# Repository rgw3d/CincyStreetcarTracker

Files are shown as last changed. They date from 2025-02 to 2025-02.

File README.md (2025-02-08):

# Cincinnati Streetcar Tracker

I learned that the real-time transit information for the Cincinnati Streetcar was published by Metro here: https://www.go-metro.com/about/developer-data/ in [GTFS](https://en.wikipedia.org/wiki/GTFS) form. 

And then I saw https://www.traintrackr.io/ and was inspired to make a version for Cincinnati. 

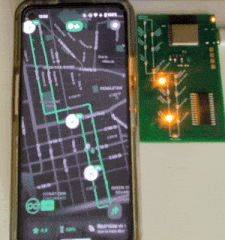
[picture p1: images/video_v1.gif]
Gif of the board in action

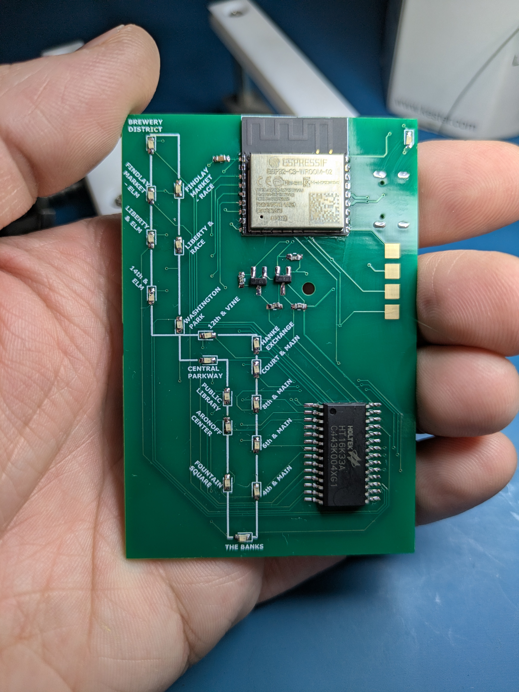
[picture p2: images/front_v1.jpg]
Front of the V1 board

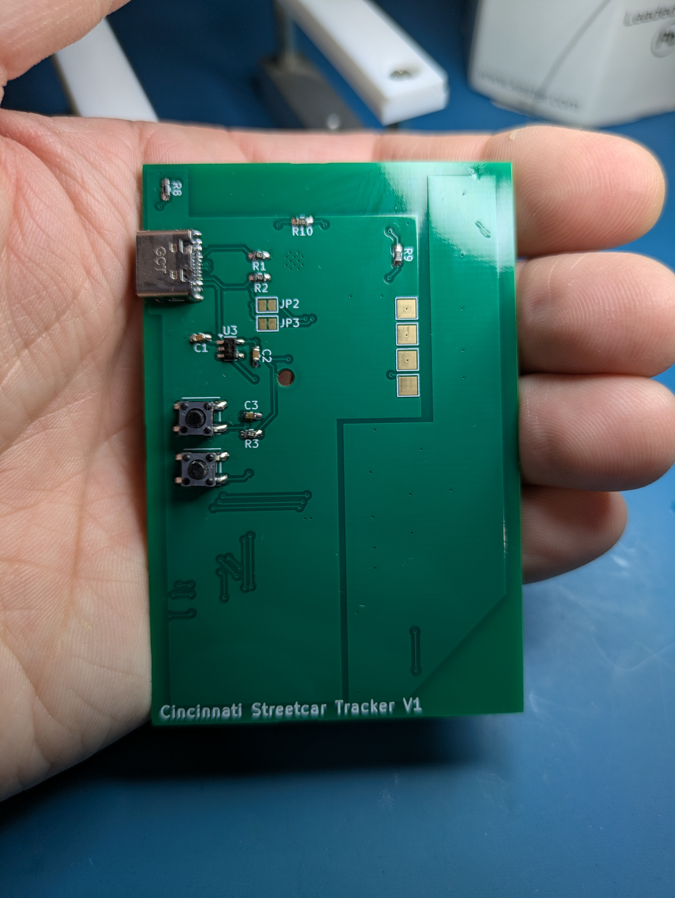
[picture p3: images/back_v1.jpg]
Back of the V1 board


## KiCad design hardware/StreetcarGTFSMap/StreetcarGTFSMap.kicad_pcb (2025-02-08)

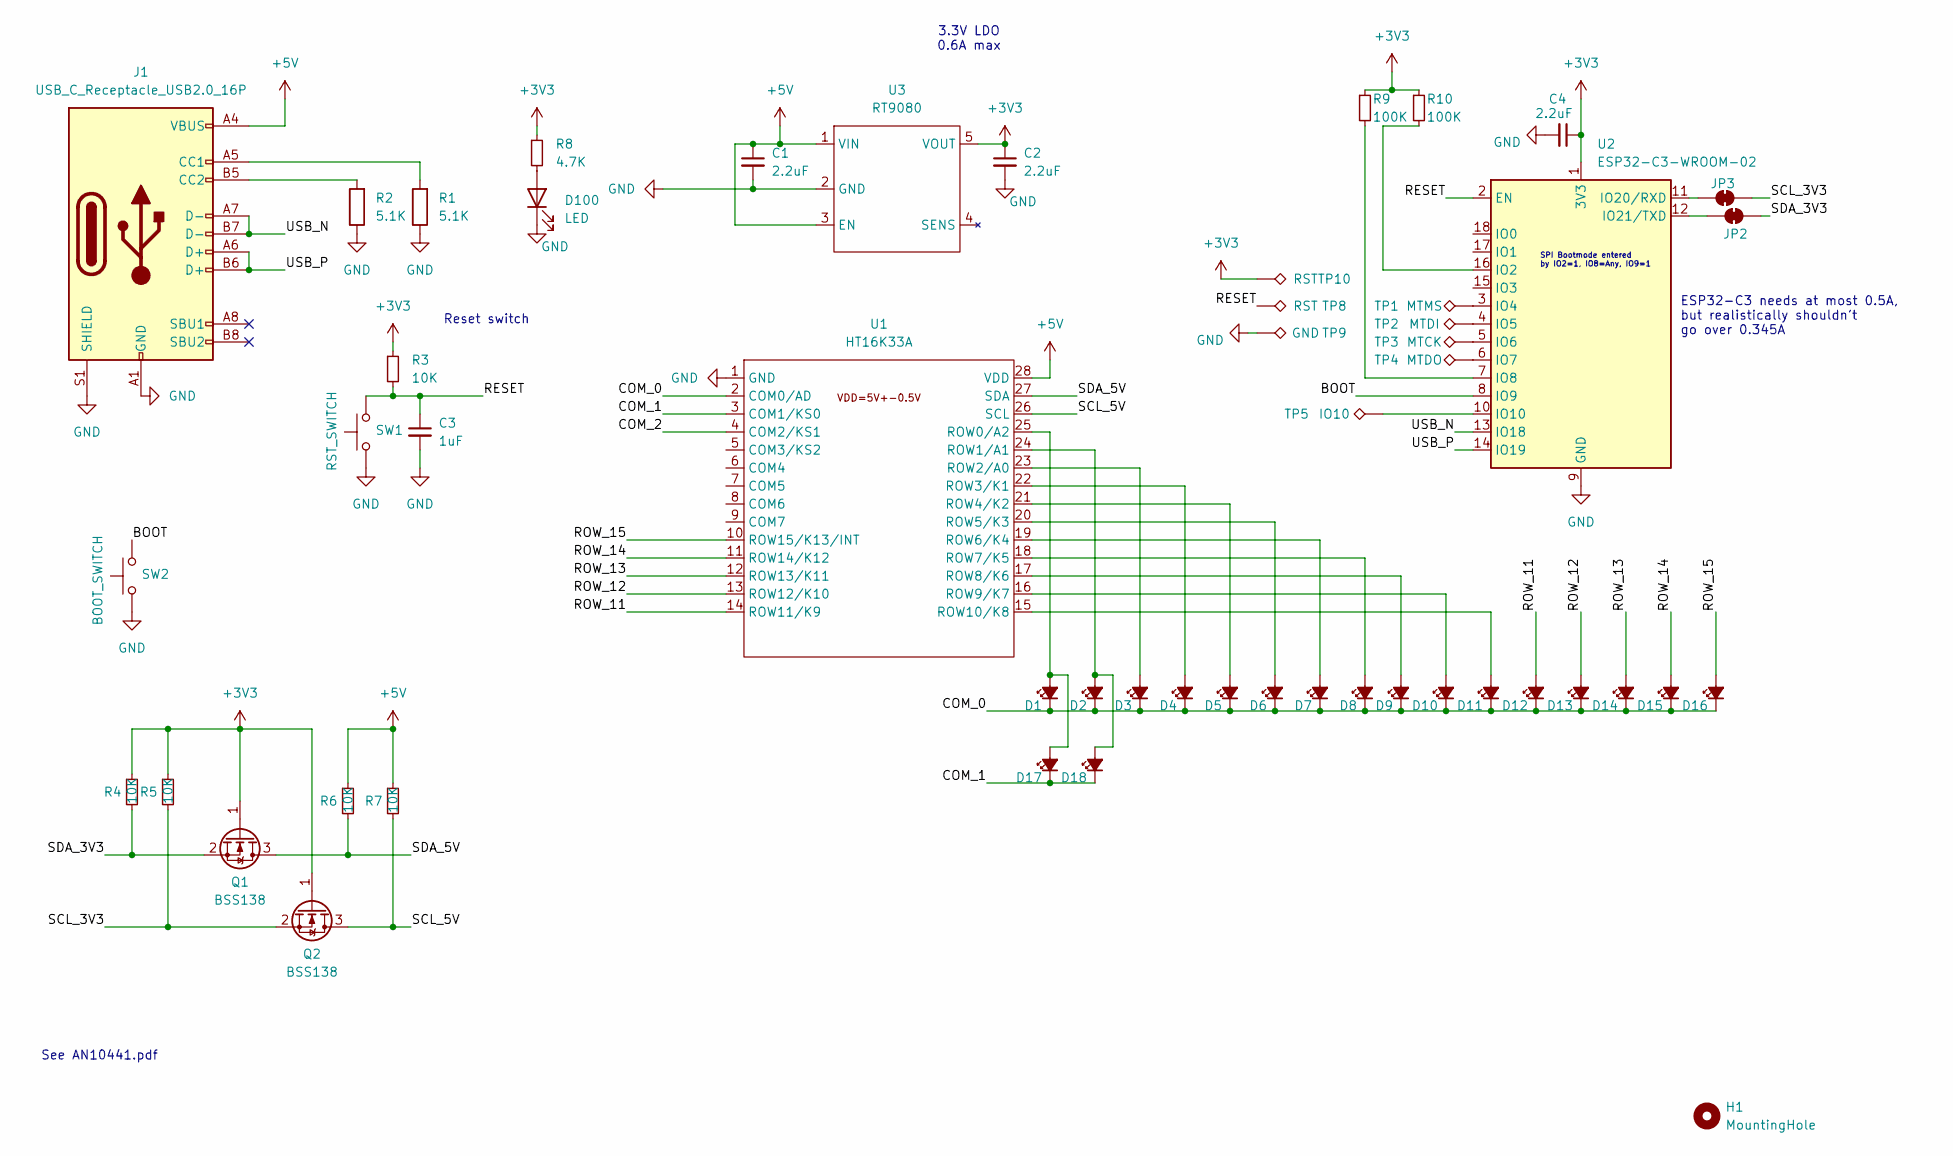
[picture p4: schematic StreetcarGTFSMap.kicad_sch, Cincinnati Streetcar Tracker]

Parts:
C1, C2, C4: 2.2uF; C_0603_1608Metric_Pad1.08x0.95mm_HandSolder
C3: 1uF; C_0603_1608Metric_Pad1.08x0.95mm_HandSolder
D1, D2, D3, D4, D5, D6, D7, D8, D9, D10, D11, D12, D13, D14, D15, D16, D17, D18: LED_Small_Filled; LED_0603_1608Metric_Pad1.05x0.95mm_HandSolder
D100: LED; LED_0603_1608Metric_Pad1.05x0.95mm_HandSolder
H1: MountingHole; MountingHole_2.1mm
J1: USB_C_Receptacle_USB2.0_16P; USB_C_Receptacle_GCT_USB4105-xx-A_16P_TopMnt_Horizontal
JP2, JP3: SolderJumper_2_Bridged; SolderJumper-2_P1.3mm_Bridged_Pad1.0x1.5mm
Q1, Q2: BSS138; SOT-23_Handsoldering
R1, R2: 5.1K; R_0603_1608Metric_Pad0.98x0.95mm_HandSolder
R3, R4, R5, R6, R7: 10K; R_0603_1608Metric_Pad0.98x0.95mm_HandSolder
R8: 4.7K; R_0603_1608Metric_Pad0.98x0.95mm_HandSolder
R9, R10: 100K; R_0603_1608Metric_Pad0.98x0.95mm_HandSolder
SW1: RST_SWITCH; SW_SPST_PTS647_Sx50
SW2: BOOT_SWITCH; SW_SPST_PTS647_Sx50
TP1: MTMS; TestPoint_Pad_2.5x2.5mm
TP2: MTDI; TestPoint_Pad_2.5x2.5mm
TP3: MTCK; TestPoint_Pad_2.5x2.5mm
TP4: MTDO; TestPoint_Pad_2.5x2.5mm
TP5: IO10; TestPoint_Pad_2.5x2.5mm
TP8, TP10: RST; TestPoint_Pad_2.5x2.5mm
TP9: GND; TestPoint_Pad_2.5x2.5mm
U1: HT16K33A; SOP-28_8.4x18.16mm_P1.27mm
U2: ESP32-C3-WROOM-02
U3: RT9080; TSOT-23-5

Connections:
+3V3: C2.1, C4.1, Q1.1 (G), Q2.1 (G), R3.1, R4.1, R5.1, R8.1, R9.1, R10.1, TP10.1, U2.1 (3V3), U3.5 (VOUT)
+5V: C1.1, J1.A4 (VBUS), J1.A9 (VBUS), J1.B4 (VBUS), J1.B9 (VBUS), R6.1, R7.1, U1.28 (VDD), U3.1 (VIN), U3.3 (EN)
/BOOT: SW2.2, U2.8 (IO9)
/COM_0: D1.1 (K), D2.1 (K), D3.1 (K), D4.1 (K), D5.1 (K), D6.1 (K), D7.1 (K), D8.1 (K), D9.1 (K), D10.1 (K), D11.1 (K), D12.1 (K), D13.1 (K), D14.1 (K), D15.1 (K), D16.1 (K), U1.2 (COM0/AD)
/COM_1: D17.1 (K), D18.1 (K), U1.3 (COM1/KS0)
/COM_2: U1.4 (COM2/KS1)
/RESET: C3.1, R3.2, SW1.2, TP8.1, U2.2 (EN)
/ROW_11: D12.2 (A), U1.14 (ROW11/K9)
/ROW_12: D13.2 (A), U1.13 (ROW12/K10)
/ROW_13: D14.2 (A), U1.12 (ROW13/K11)
/ROW_14: D15.2 (A), U1.11 (ROW14/K12)
/ROW_15: D16.2 (A), U1.10 (ROW15/K13/INT)
/SCL_3V3: JP3.2 (B), Q2.2 (S), R5.2
/SCL_5V: Q2.3 (D), R7.2, U1.26 (SCL)
/SDA_3V3: JP2.2 (B), Q1.2 (S), R4.2
/SDA_5V: Q1.3 (D), R6.2, U1.27 (SDA)
/USB_N: J1.A7 (D-), J1.B7 (D-), U2.13 (IO18)
/USB_P: J1.A6 (D+), J1.B6 (D+), U2.14 (IO19)
GND: C1.2, C2.2, C3.2, C4.2, D100.1 (K), J1.A1 (GND), J1.A12 (GND), J1.B1 (GND), J1.B12 (GND), J1.S1 (SHIELD), R1.1, R2.1, SW1.1, SW2.1, TP9.1, U1.1 (GND), U2.9 (GND), U2.19 (GND), U3.2 (GND)
unnamed: D1.2 (A), D17.2 (A), U1.25 (ROW0/A2)
unnamed: D3.2 (A), U1.23 (ROW2/A0)
unnamed: D4.2 (A), U1.22 (ROW3/K1)
unnamed: D5.2 (A), U1.21 (ROW4/K2)
unnamed: D6.2 (A), U1.20 (ROW5/K3)
unnamed: D7.2 (A), U1.19 (ROW6/K4)
unnamed: D8.2 (A), U1.18 (ROW7/K5)
unnamed: D9.2 (A), U1.17 (ROW8/K6)
unnamed: D10.2 (A), U1.16 (ROW9/K7)
unnamed: D11.2 (A), U1.15 (ROW10/K8)
unnamed: D2.2 (A), D18.2 (A), U1.24 (ROW1/A1)
unnamed: D100.2 (A), R8.2
unnamed: J1.A5 (CC1), R1.2
unnamed: J1.B5 (CC2), R2.2
unnamed: JP2.1 (A), U2.12 (IO21/TXD)
unnamed: JP3.1 (A), U2.11 (IO20/RXD)
unnamed: R10.2, U2.16 (IO2)
unnamed: TP1.1, U2.3 (IO4)
unnamed: TP2.1, U2.4 (IO5)
unnamed: TP3.1, U2.5 (IO6)
unnamed: TP4.1, U2.6 (IO7)
unnamed: R9.2, U2.7 (IO8)
unnamed: TP5.1, U2.10 (IO10)

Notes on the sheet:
Reset switch
3.3V LDO 0.6A max
ESP32-C3 needs at most 0.5A, but realistically shouldn't go over 0.345A
See AN10441.pdf
SPI Bootmode entered by IO2=1, IO8=Any, IO9=1

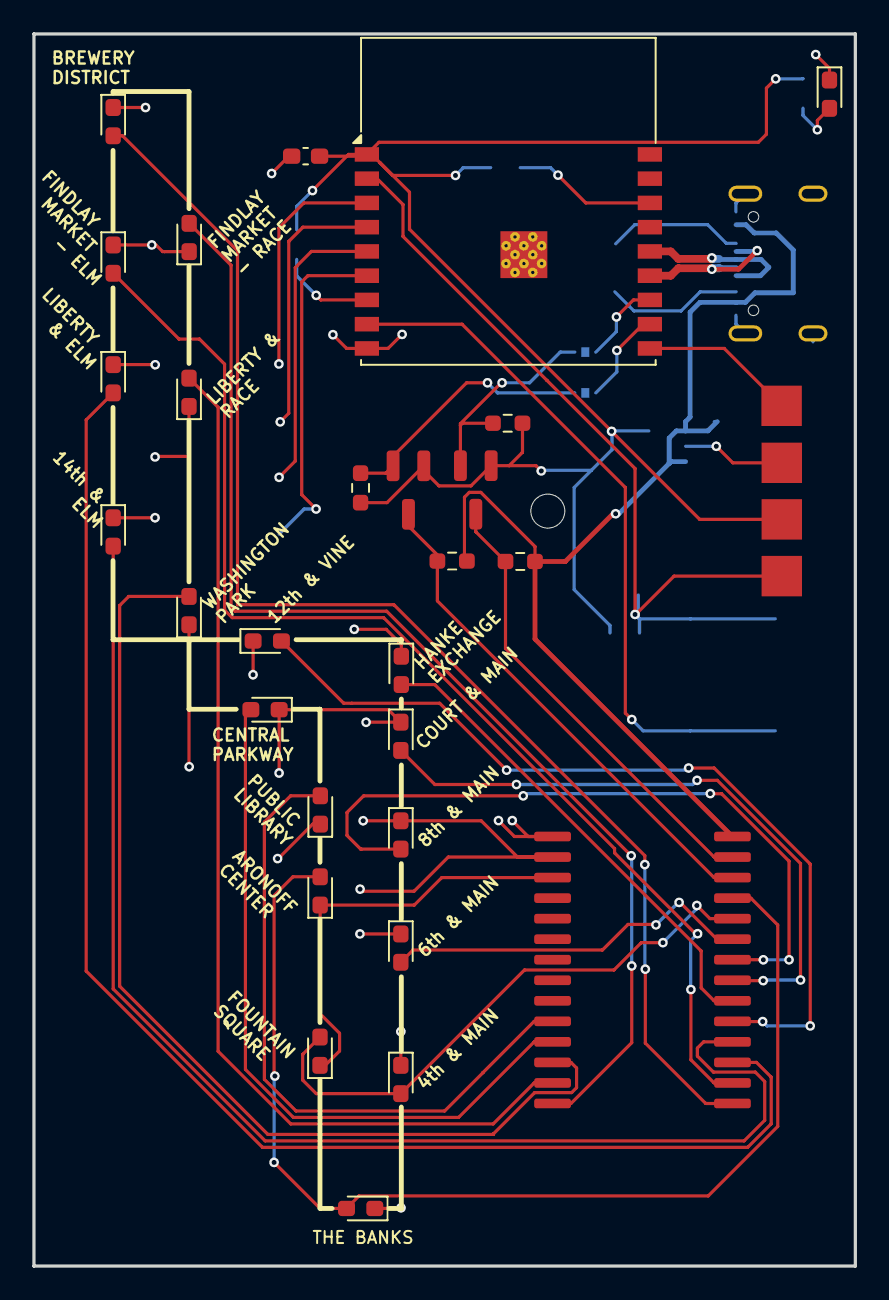
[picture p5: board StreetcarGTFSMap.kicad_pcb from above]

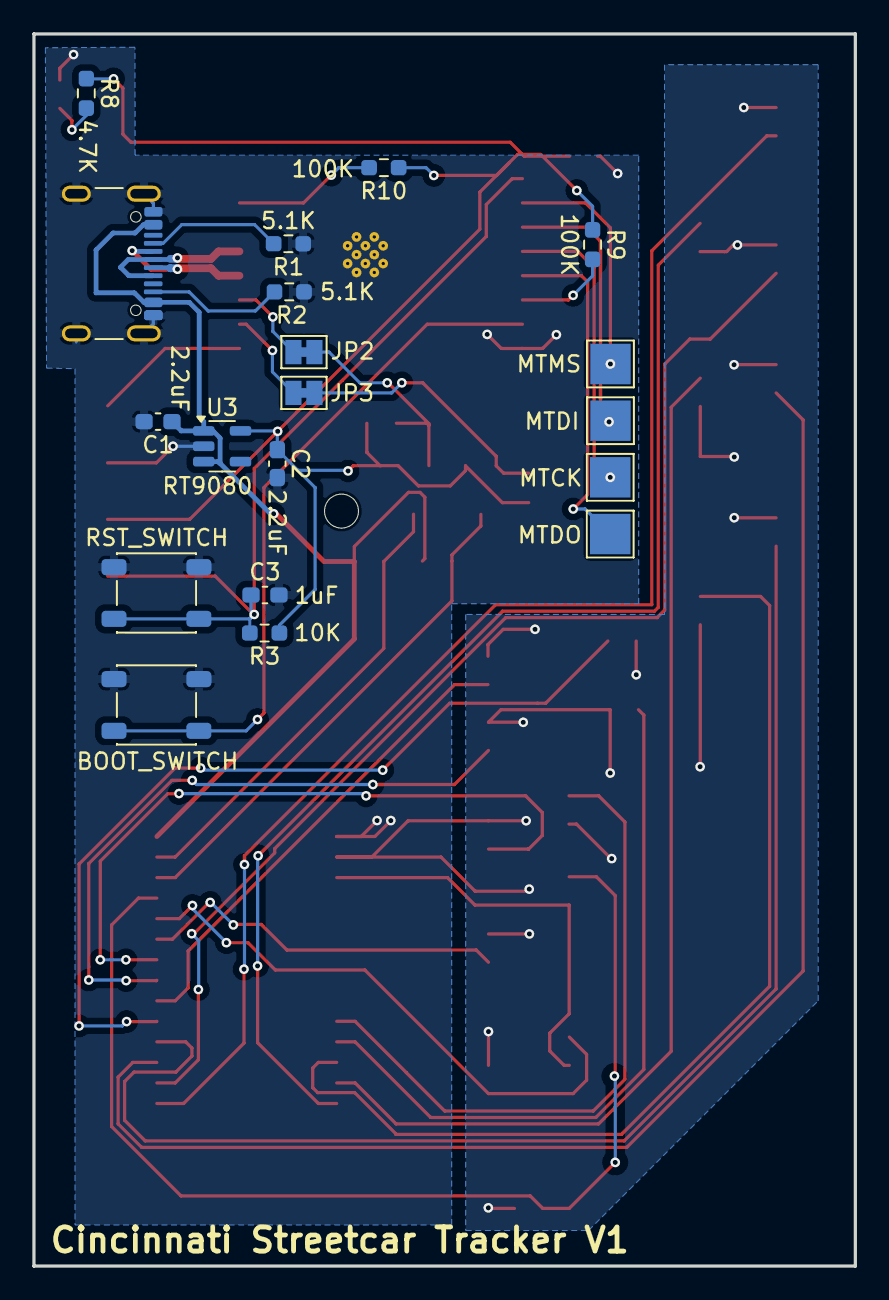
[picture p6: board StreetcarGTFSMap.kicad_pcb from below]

Board: 2 copper layers, 50.8 x 76.2 mm, 52 parts (19 on the bottom side), 41 nets.

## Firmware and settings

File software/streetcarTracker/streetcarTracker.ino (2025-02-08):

#include <WiFi.h>
#include <NetworkClientSecure.h>
#define PB_BUFFER_ONLY 1
#include <SnappyProto.h>
#include "proto/pb.h"
#include "proto/pb_decode.h"  // Don't need to include pb_encode.h
#include "gtfs-realtime.pb.h"
#include "boundingBox.h"

#include <Wire.h>
#include <Adafruit_GFX.h>
#include "Adafruit_LEDBackpack.h"

//int ledPin = 10;

const long bufferLength = 32384;
uint8_t buffer[bufferLength];
const char *ssid = "JohnWiFi";
const char *password = "cleverpassword";


// Map all Bounding boxes to column/row
// Some of these overlap
// http://bboxfinder.com
static const Mapping stationMapping[] = {
  Mapping(BoundingBox(-84.511739, 39.097893, -84.510334, 39.100775), 7, 0),   // The Banks
  Mapping(BoundingBox(-84.510623, 39.097894, -84.509411, 39.098706), 7, 0),   // The Banks
  Mapping(BoundingBox(-84.509395, 39.097890, -84.508697, 39.099318), 7, 1),   // 4th & Main
  Mapping(BoundingBox(-84.509990, 39.099259, -84.508569, 39.100830), 7, 1),   // 4th & Main
  Mapping(BoundingBox(-84.510441, 39.100823, -84.508681, 39.103402), 7, 2),   // 6th & Main
  Mapping(BoundingBox(-84.511042, 39.103396, -84.509583, 39.105487), 7, 3),   // 8th & Main
  Mapping(BoundingBox(-84.511482, 39.105479, -84.510216, 39.107262), 7, 4),   // Court & Main
  Mapping(BoundingBox(-84.511760, 39.107242, -84.510494, 39.108609), 7, 5),   // Hanke Exchange
  Mapping(BoundingBox(-84.514958, 39.108148, -84.511734, 39.108808), 7, 6),   // 12th & Vine
  Mapping(BoundingBox(-84.511830, 39.108642, -84.511267, 39.108913), 7, 6),   // 12th & Vine
  Mapping(BoundingBox(-84.516309, 39.108035, -84.514952, 39.108451), 7, 7),   // 14th & Elm
  Mapping(BoundingBox(-84.517297, 39.107805, -84.516535, 39.108200), 7, 7),   // 14th & Elm
  Mapping(BoundingBox(-84.518938, 39.107540, -84.517227, 39.110017), 7, 7),   // 14th & Elm
  Mapping(BoundingBox(-84.520022, 39.109897, -84.518391, 39.113046), 7, 8),   // Liberty & Elm
  Mapping(BoundingBox(-84.520258, 39.112970, -84.518788, 39.115153), 7, 9),   // Findlay Market - Elm
  Mapping(BoundingBox(-84.520698, 39.115060, -84.519217, 39.117334), 7, 10),  // Brewery District
  Mapping(BoundingBox(-84.521057, 39.117329, -84.518434, 39.118287), 7, 11),  // Findlay Market - Race
  Mapping(BoundingBox(-84.519013, 39.115488, -84.517801, 39.117479), 7, 11),  // Findlay Market - Race
  Mapping(BoundingBox(-84.518434, 39.112501, -84.516985, 39.115558), 7, 12),  // Liberty & Race
  Mapping(BoundingBox(-84.517640, 39.108127, -84.516309, 39.112611), 7, 13),  // Washington Park
  Mapping(BoundingBox(-84.516444, 39.106691, -84.513981, 39.108012), 7, 14),  // Central Parkway
  Mapping(BoundingBox(-84.513992, 39.105184, -84.512056, 39.107365), 7, 15),  // Public Library
  Mapping(BoundingBox(-84.512587, 39.103953, -84.511836, 39.105245), 6, 0),   // Aronoff Center
  Mapping(BoundingBox(-84.512297, 39.100471, -84.510956, 39.104003), 6, 1),   // Fountain Square
};

constexpr size_t stationMappingLength = sizeof(stationMapping) / sizeof(stationMapping[0]);
static_assert(stationMappingLength == 24);

#ifndef _BV
#define _BV(bit) (1 << (bit))
#endif

Adafruit_8x16matrix matrix = Adafruit_8x16matrix();
uint16_t tempIncomingDisplayBuffer[8];

static const uint8_t PROGMEM
  test1[] = {
    B11111111,
    B00000000,
    B11111111,
    B00000000,
    B11111111,
    B00000000,
    B11111111,
    B00000000,
    B11111111,
    B00000000,
    B11111111,
    B00000000,
    B11111111,
    B00000000,
    B11111111,
    B00000000,
  },
  test2[] = {
    B00000000,
    B11111111,
    B00000000,
    B11111111,
    B00000000,
    B11111111,
    B00000000,
    B11111111,
    B00000000,
    B11111111,
    B00000000,
    B11111111,
    B00000000,
    B11111111,
    B00000000,
    B11111111,
  };



void setup() {
  // put your setup code here, to run once:
  Serial.begin(115200);
  delay(10);
  Serial.println("Starting matrix...");
  bool ret = Wire.setPins(21, 20);
  Serial.println("Success setting pins " + String(ret));
  ret = matrix.begin(0x70);
  Serial.println("Success beginning matrix " + String(ret));

  Serial.println();
  Serial.println();
  Serial.print("Waiting for WiFi...");
  // We start by connecting to a WiFi network
  WiFi.begin(ssid, password);
  while (WiFi.status() != WL_CONNECTED) {
    delay(500);
    Serial.print(".");
  }


  Serial.println("");
  Serial.println("WiFi connected");
  Serial.println("IP address: ");
  Serial.println(WiFi.localIP());

  matrix.drawBitmap(0, 0, test1, 8, 16, LED_ON);
  matrix.writeDisplay();
  Serial.println("printed first");
  delay(500);

  matrix.clear();
  matrix.writeDisplay();
  Serial.println("cleared");
  delay(200);

  matrix.drawBitmap(0, 0, test2, 8, 16, LED_ON);
  matrix.writeDisplay();
  Serial.println("printed second");
  delay(500);

  matrix.clear();
  matrix.writeDisplay();
  Serial.println("cleared");
  delay(200);
}

uint8_t counter = 0;

bool decodeTripId(pb_istream_t *stream, const pb_field_t *field, void **arg) {
  size_t len = stream->bytes_left;
  // Read string into the allocated buffer
  if (!pb_read(stream, (pb_byte_t *)*arg, std::min(len, (size_t)19))) {
    return false;
  }

  return true;
}

bool decodeEntity(pb_istream_t *stream, const pb_field_t *field, void **arg) {
  transit_realtime_FeedEntity feedEntity = transit_realtime_FeedEntity_init_zero;
  char id[20];
  char tripId[20];
  memset(tripId, 0, 20);
  memset(id, 0, 20);
  feedEntity.id.funcs.decode = &decodeTripId;
  feedEntity.id.arg = &id;
  feedEntity.vehicle.trip.route_id.funcs.decode = &decodeTripId;
  feedEntity.vehicle.trip.route_id.arg = &tripId;
  if (!pb_decode(stream, transit_realtime_FeedEntity_fields, &feedEntity)) {
    Serial.println(String("Decoding faile Feed Entity!: ") + String(PB_GET_ERROR(stream)));
    return false;
  }
  // The streetcar is route 100. The protobuf looks like:
  /*
  entity {
  id: "1178B"
  vehicle {
    trip {
      trip_id: "1708906"
      start_date: "20241227"
      route_id: "100"
    }
  ... }
  */
  String stringTripId(tripId);
  if (stringTripId == "100" && feedEntity.has_vehicle && feedEntity.vehicle.has_position) {

    double lat = feedEntity.vehicle.position.latitude;
    double lon = feedEntity.vehicle.position.longitude;

    //Serial.println("Found Streetcar at position (lon, lat) " + String(lon) + ", " + String(lat));

    for (int i = 0; i < stationMappingLength; i++) {
      int col = stationMapping[i].m_col;
      int row = stationMapping[i].m_row;
      if (stationMapping[i].m_bb.contains(lon, lat)) {
        Serial.println("ID: " + String(id) + " Route: " + stringTripId + " within bb for col " + String(col) + " row: " + String(row));
        tempIncomingDisplayBuffer[7 - col] |= _BV(row);
      }
    }
  }

  return true;
}

void loop() {
  //matrix.clear();
  //matrix.writeDisplay();
  //Serial.println("cleared");
  //delay(200);


  const uint16_t port = 443;
  const char *host = "tmgtfsprd.sorttrpcloud.com";  // ip or dns

  Serial.print("Connecting to ");
  Serial.println(host);

  // Use NetworkClient class to create TCP connections
  NetworkClientSecure client;
  client.setInsecure();  //skip verification

  if (!client.connect(host, port)) {
    Serial.println("Connection failed.");
    Serial.println("Waiting 5 seconds before retrying...");
    delay(5000);
    return;
  }

  String footer = String(" HTTP/1.1\r\n") + "Host: " + String(host) + "\r\n" + "Connection: close\r\n\r\n";

  //client.print("GET /TMGTFSRealTimeWebService/vehicle/vehiclepositions.pb HTTP/1.1\r\nHost: tmgtfsprd.sorttrpcloud.com\r\nCustomUserAgent/1.0\r\nAccept: */*\r\nConnection: close\r\n\r\n");
  client.print("GET /TMGTFSRealTimeWebService/vehicle/vehiclepositions.pb" + footer);


  int maxloops = 0;

  //wait for the server's reply to become available
  while (!client.available() && maxloops < 1000) {
    maxloops++;
    delay(1);  //delay 1 msec
  }

  if (client.available() == 0) {
    Serial.println("client.available() timed out ");
    client.stop();
    return;
  }

  // 1) Search output for "Content-Length",
  // 2) Parse the content length
  // 3) Skip to the end of the header (look for \r\n\r\n)
  // 4) Read the remaining buffer
  // and then
  while (client.available() > 0) {
    // Each line should be terminated with "\r\n"
    String line = client.readStringUntil('\r');
    if (line.startsWith("\nContent-Length: ")) {
      long payloadLength = line.substring(17).toInt();
      Serial.println("ContentLength: " + String(payloadLength));
      while (client.available() > 0) {
        line = client.readStringUntil('\n');
        if (line == "\r") {
          // The end of the header is marked with "\r\n\r\n"
          // If we are here we've advanced to the final "\n", so the rest of the buffer should be the payload
          break;
        }
      }
      if (client.available() >= payloadLength && bufferLength >= payloadLength) {
        client.readBytes(buffer, payloadLength);
      } else {
        Serial.println("Specified payloadLength exceeds available buffer size: " + String(client.available()) + " Or maxBuffer length: " + String(bufferLength));
        break;
      }

      /* Allocate space for the decoded message. */
      transit_realtime_FeedMessage message = transit_realtime_FeedMessage_init_zero;
      message.entity.funcs.decode = &decodeEntity;
      message.entity.arg = nullptr;

      /* Create a stream that reads from the buffer. */
      pb_istream_t stream = pb_istream_from_buffer(buffer, payloadLength);

      for (int i = 0; i < 8; i++) {
        tempIncomingDisplayBuffer[i] = 0;
      }
      /* Now we are ready to decode the message. */
      int status = pb_decode(&stream, transit_realtime_FeedMessage_fields, &message);
      if (!status) {
        Serial.println("ERROR: pb_decode status: " + String(status));
        return;  // error condition
      }
      Serial.println("msg timestamp: " + String(message.header.timestamp));
      // Overlay updated positions on top of existing positions to give a sense of movement.
      for (int i = 0; i < 8; i++) {
        matrix.displaybuffer[i] |= tempIncomingDisplayBuffer[i];
      }
      matrix.writeDisplay();
      delay(2000);
      // Now we display only new positions.
      for (int i = 0; i < 8; i++) {
        matrix.displaybuffer[i] = tempIncomingDisplayBuffer[i];
      }
      matrix.writeDisplay();

      break;
    }
  }

  //Serial.println("Closing connection.");
  client.stop();

  Serial.println("Waiting 10 seconds before restarting...");
  delay(10000);
}
